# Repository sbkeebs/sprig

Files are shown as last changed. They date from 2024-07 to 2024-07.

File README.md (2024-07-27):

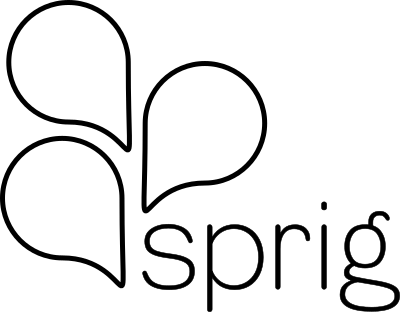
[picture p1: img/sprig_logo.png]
sprig logo


★ 10 columns in a modified Katana layout

★ inner columns are moved down a bit for an ergo-light curve

★ spacebar layout supports ISO enter for either or both bars

### This repo should contain:
- KiCAD 8 files for the PCB
- production files (gerbers, JLC BOM, CPL, etc) -- definitely double check the part numbers/availability before committing to fabrication! 
- printable files for the case (i am not very experienced in 3D design, but i have confirmed that it works!)
- firmware in both qmk/vial and zmk, and source for each

### To build your own zmk keymap
Fork [this repo](https://github.com/sbkeebs/sprig-zmk-config), and enable Actions. Modify `config/boards/arm/sprig/sprig.keymap`. Let it build (click Actions at the top of your repo).

ZMK Studio is not yet integrated!

This was built upon NCKiser's [STM32F072 template](https://github.com/NCKiser/STM32F072_template) as one of my first projects with an integrated MCU. If you'd like to get started with your own keyboard, [this video](https://www.youtube.com/watch?v=kGKN8SGkUD0) is a great place to start.

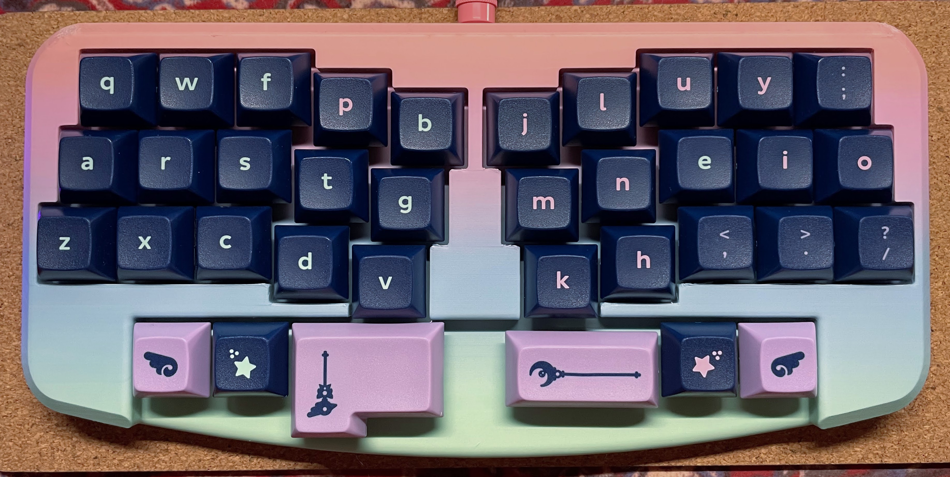
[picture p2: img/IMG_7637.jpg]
photo of sprig


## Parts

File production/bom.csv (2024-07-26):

Designator | Footprint | Quantity | Value | LCSC Part #
BOOT1, RST1 | SW_SPST_TL3342 | 2 | SW_SPST | C318884
C1, C3, C4, C5, C6, C7, C8 | 0402 | 7 | 100nF | C1525
C10, C9 | 0402 | 2 | 1uF | C52923
C2 | 0603 | 1 | 10uF | C57112
D1, D10, D11, D12, D13, D14, D15, D16, D17, D18, D19, D2, D20, D21, D22, D23, D24, D25, D26, D27, D28, D29, D3, D30, D32, D33, D34, D35, D36, D37, D4, D5, D6, D7, D8, D9 | D_SOD-323 | 36 | D_Small | C908234
F1 | 1206 | 1 | 500mA | C70076
J1 | USB_C_Receptacle_HRO_TYPE-C-31-M-12 | 1 | USB_C_Receptacle_USB2.0 | C165948
R1, R2, R3, R4 | 0402 | 4 | 5.1k | C144745
U1 | LQFP-48_7x7mm_P0.5mm | 1 | STM32F072CBT6 | C81720
U2 | SOT-143 | 1 | PRTR5V0U2X | C2827688
U3 | SOT-23 | 1 | XC6206PxxxMR-Regulator_Linear | C5446

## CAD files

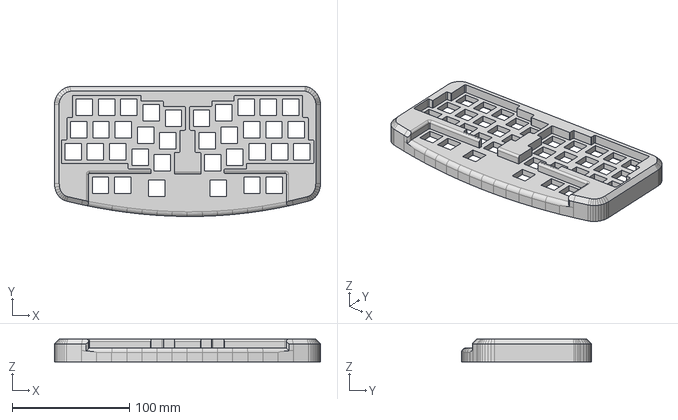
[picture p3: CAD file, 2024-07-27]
case/sprig_top_case.step
227.1 x 111.0 x 19.5 mm

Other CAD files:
case/sprig_top_case.stl

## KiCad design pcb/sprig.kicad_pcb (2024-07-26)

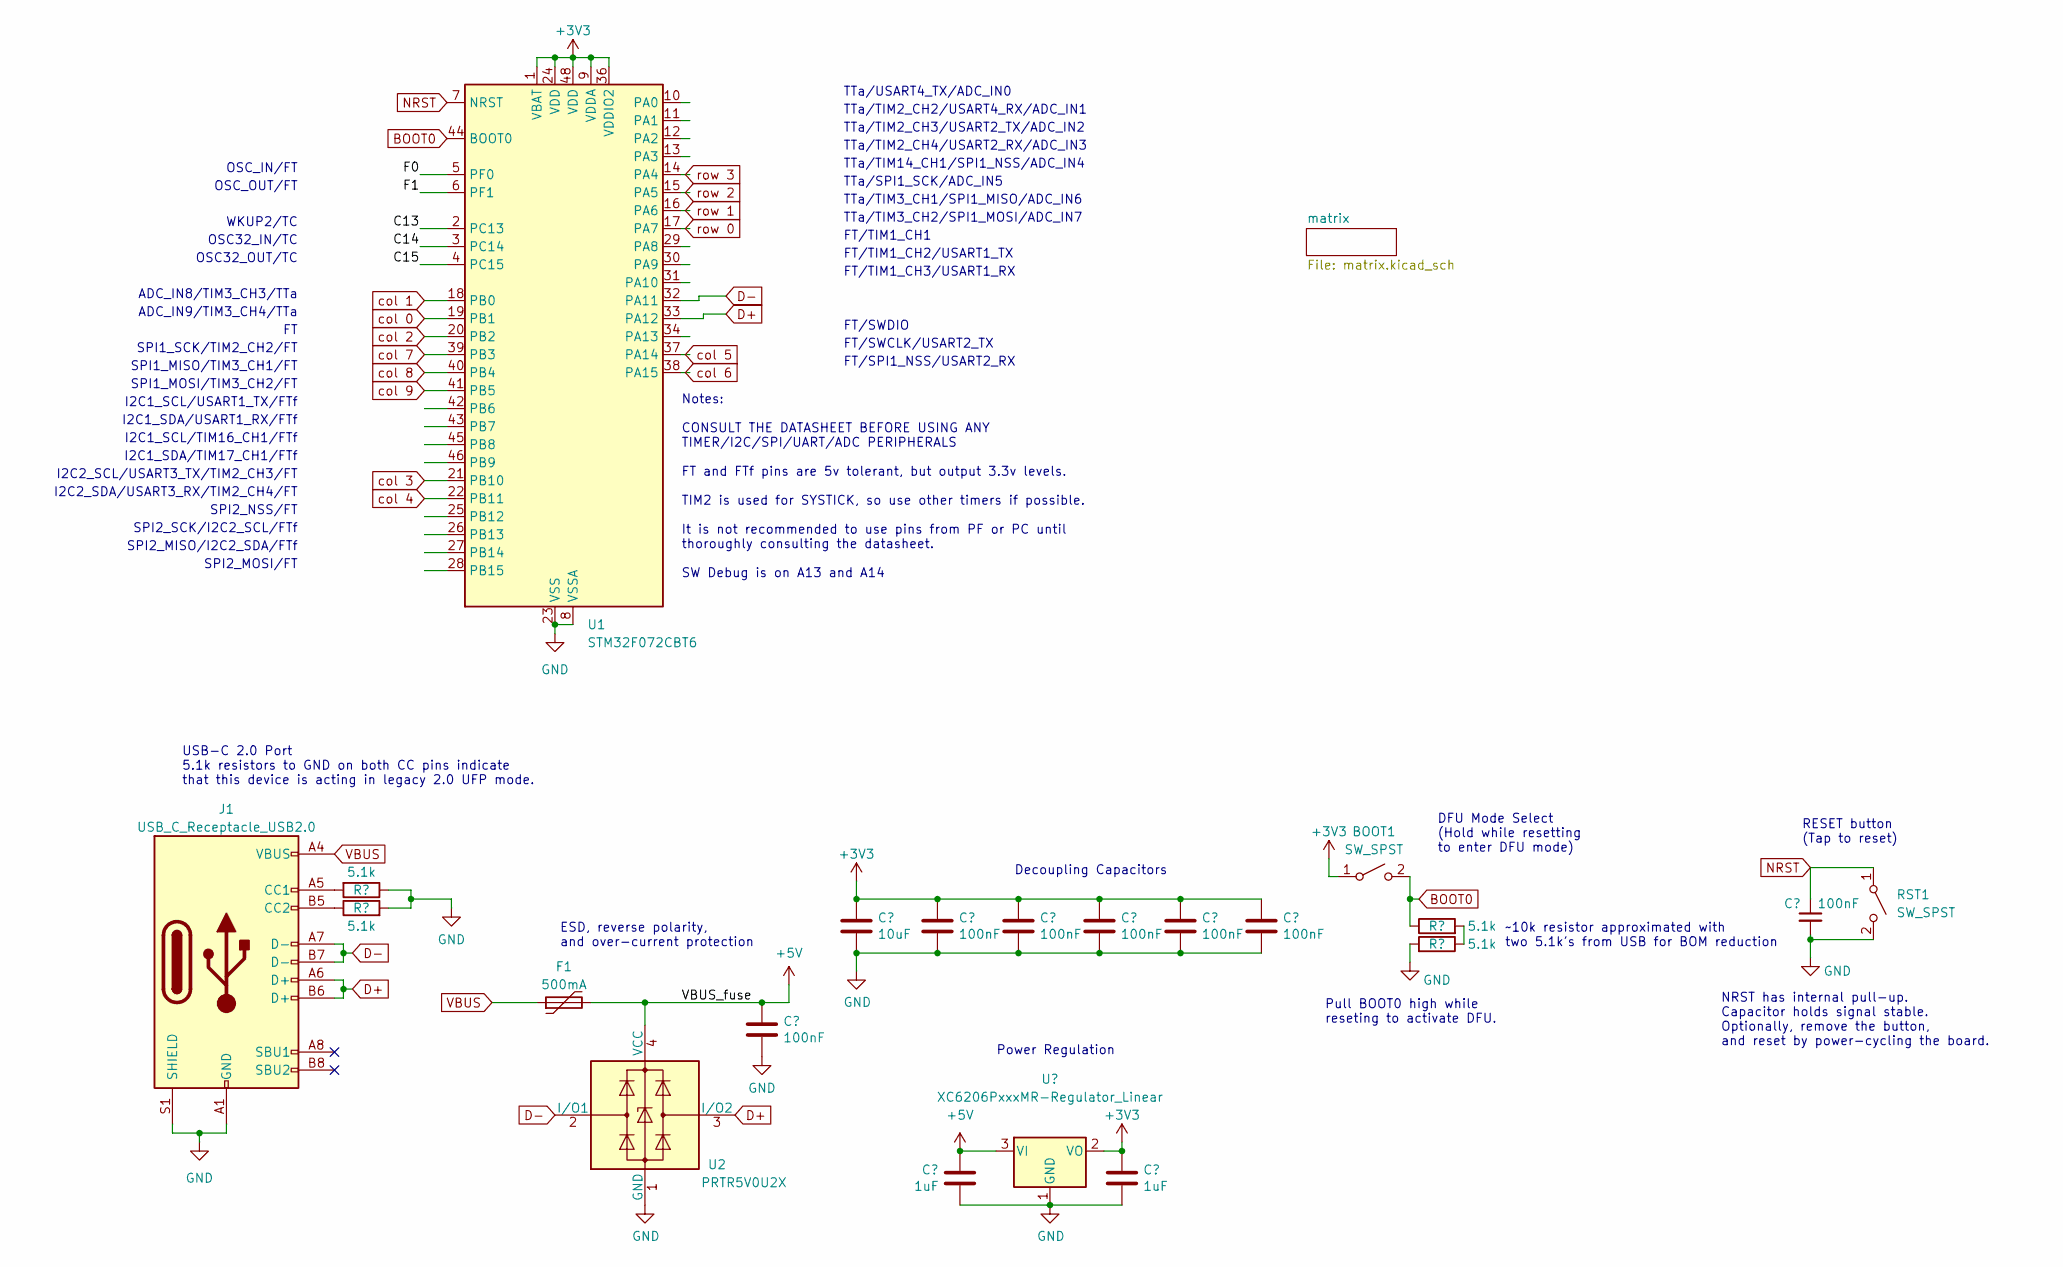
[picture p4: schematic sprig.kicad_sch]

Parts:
BOOT1: SW_SPST; SW_SPST_TL3342
C1, C3, C4, C5, C6, C7, C8: 100nF; C_0402_1005Metric; LCSC C307331
C2: 10uF; C_0603_1608Metric; LCSC C307331
C9, C10: 1uF; C_0402_1005Metric; LCSC C307331
F1: 500mA; Fuse_1206_3216Metric; LCSC C135341
J1: USB_C_Receptacle_USB2.0; USB_C_Receptacle_HRO_TYPE-C-31-M-12; JlcRotOffset 180
R1, R2, R3, R4: 5.1k; R_0402_1005Metric
RST1: SW_SPST; SW_SPST_TL3342
U1: STM32F072CBT6; LQFP-48_7x7mm_P0.5mm; JlcRotOffset 90
U2: PRTR5V0U2X; SOT-143; LCSC C2827688
U3: XC6206PxxxMR-Regulator_Linear; SOT-23; LCSC C5446

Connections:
+3V3: BOOT1.1 (A), C2.1, C3.1, C4.1, C5.1, C6.1, C7.1, C10.1, U1.1 (VBAT), U1.9 (VDDA), U1.24 (VDD), U1.36 (VDDIO2), U1.48 (VDD), U3.2 (VO)
+5V: C8.1, C9.1, F1.2, U2.4 (VCC), U3.3 (VI)
/C13: U1.2 (PC13)
/C14: U1.3 (PC14)
/C15: U1.4 (PC15)
/F0: U1.5 (PF0)
/F1: U1.6 (PF1)
BOOT0: BOOT1.2 (B), R3.1, U1.44 (BOOT0)
D+: J1.A6 (D+), J1.B6 (D+), U1.33 (PA12), U2.3 (I/O2)
D-: J1.A7 (D-), J1.B7 (D-), U1.32 (PA11), U2.2 (I/O1)
GND: C1.2, C2.2, C3.2, C4.2, C5.2, C6.2, C7.2, C8.2, C9.2, C10.2, J1.A1 (GND), J1.A12 (GND), J1.B1 (GND), J1.B12 (GND), J1.S1 (SHIELD), R1.1, R2.2, R4.2, RST1.2 (B), U1.8 (VSSA), U1.23 (VSS), U1.35 (VSS), U1.47 (VSS), U2.1 (GND), U3.1 (GND)
NRST: C1.1, RST1.1 (A), U1.7 (NRST)
unnamed: J1.A5 (CC1), R1.2
unnamed: J1.B5 (CC2), R2.1
unnamed: R3.2, R4.1
VBUS: F1.1, J1.A4 (VBUS), J1.A9 (VBUS), J1.B4 (VBUS), J1.B9 (VBUS)
col 0: U1.19 (PB1); also elsewhere on the board
col 1: U1.18 (PB0); also elsewhere on the board
col 2: U1.20 (PB2); also elsewhere on the board
col 3: U1.21 (PB10); also elsewhere on the board
col 4: U1.22 (PB11); also elsewhere on the board
col 5: U1.37 (PA14); also elsewhere on the board
col 6: U1.38 (PA15); also elsewhere on the board
col 7: U1.39 (PB3); also elsewhere on the board
col 8: U1.40 (PB4); also elsewhere on the board
col 9: U1.41 (PB5); also elsewhere on the board
row 0: U1.17 (PA7); also elsewhere on the board
row 1: U1.16 (PA6); also elsewhere on the board
row 2: U1.15 (PA5); also elsewhere on the board
row 3: U1.14 (PA4); also elsewhere on the board

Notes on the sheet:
SPI1_SCK/TIM2_CH2/FT
FT/TIM1_CH1
FT/TIM1_CH3/USART1_RX
SPI2_NSS/FT
Notes: CONSULT THE DATASHEET BEFORE USING ANY TIMER/I2C/SPI/UART/ADC PERIPHERALS FT and FTf pins are 5v tolerant, but output 3.3v levels. TIM2 is used for SYSTICK, so use other timers if possible. It is not recommended to use pins from PF or PC until thoroughly consulting the datasheet. SW Debug is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
TTa/TIM2_CH4/USART2_RX/ADC_IN3
NRST has internal pull-up. Capacitor holds signal stable. Optionally, remove the button, and reset by power-cycling the board.
FT/SWDIO
Decoupling Capacitors
SPI1_MOSI/TIM3_CH2/FT
ADC_IN9/TIM3_CH4/TTa
I2C2_SCL/USART3_TX/TIM2_CH3/FT
SPI2_MISO/I2C2_SDA/FTf
FT/SWCLK/USART2_TX
I2C1_SCL/TIM16_CH1/FTf
~10k resistor approximated with two 5.1k's from USB for BOM reduction
TTa/TIM2_CH2/USART4_RX/ADC_IN1
USB-C 2.0 Port 5.1k resistors to GND on both CC pins indicate that this device is acting in legacy 2.0 UFP mode.
TTa/TIM2_CH3/USART2_TX/ADC_IN2
OSC_IN/FT
DFU Mode Select (Hold while resetting to enter DFU mode)
WKUP2/TC
I2C2_SDA/USART3_RX/TIM2_CH4/FT
ADC_IN8/TIM3_CH3/TTa
RESET button (Tap to reset)
Pull BOOT0 high while reseting to activate DFU.
I2C1_SDA/TIM17_CH1/FTf
TTa/SPI1_SCK/ADC_IN5
TTa/TIM3_CH1/SPI1_MISO/ADC_IN6
TTa/TIM3_CH2/SPI1_MOSI/ADC_IN7
OSC32_OUT/TC
FT/SPI1_NSS/USART2_RX
SPI1_MISO/TIM3_CH1/FT
OSC32_IN/TC
TTa/TIM14_CH1/SPI1_NSS/ADC_IN4
I2C1_SDA/USART1_RX/FTf
SPI2_MOSI/FT
FT/TIM1_CH2/USART1_TX
Power Regulation
SPI2_SCK/I2C2_SCL/FTf

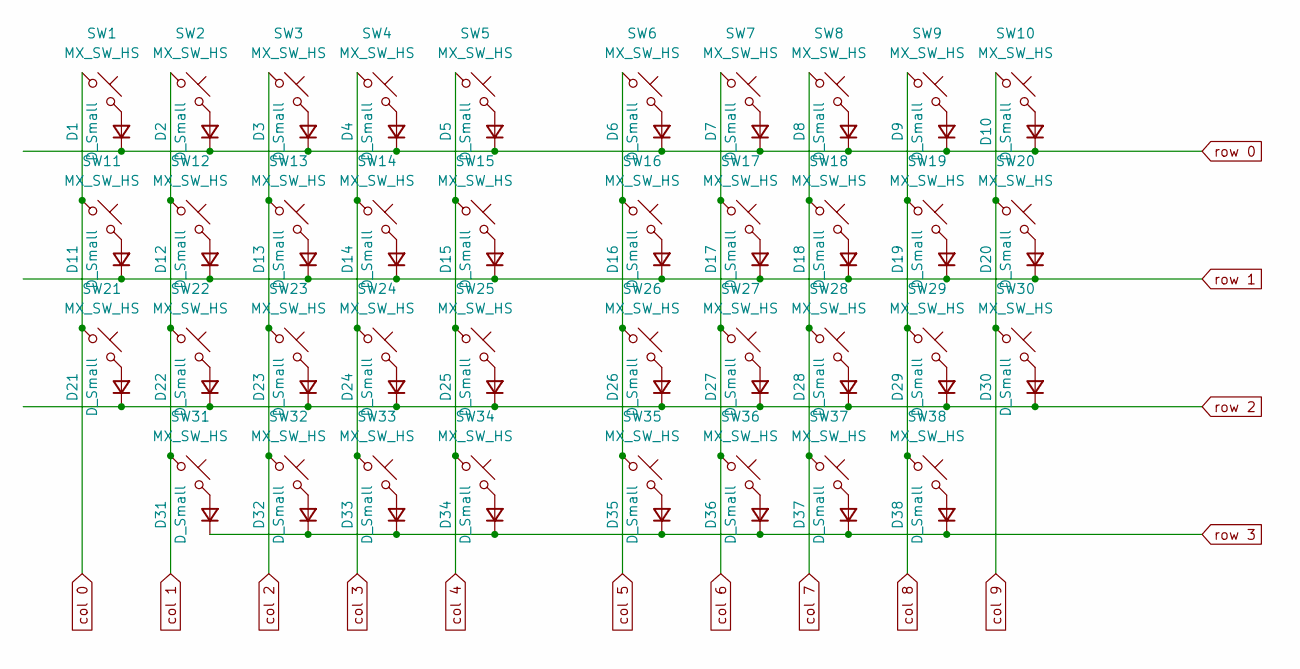
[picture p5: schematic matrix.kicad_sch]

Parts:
D1, D2, D3, D4, D5, D6, D7, D8, D9, D10, D11, D12, D13, D14, D15, D16, D17, D18, D19, D20, D21, D22, D23, D24, D25, D26, D27, D28, D29, D30, D31, D32, D33, D34, D35, D36, D37, D38: D_Small; D_SOD-323
SW1, SW2, SW3, SW4, SW5, SW6, SW7, SW8, SW9, SW10, SW11, SW12, SW13, SW14, SW15, SW16, SW17, SW18, SW19, SW20, SW21, SW22, SW23, SW24, SW25, SW26, SW27, SW28, SW29, SW30, SW31, SW32, SW33, SW34, SW35, SW36, SW37, SW38: MX_SW_HS; SW_MX_HS_CPG151101S11_1u

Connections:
unnamed: D1.2 (A), SW1.2
unnamed: D2.2 (A), SW2.2
unnamed: D3.2 (A), SW3.2
unnamed: D4.2 (A), SW4.2
unnamed: D5.2 (A), SW5.2
unnamed: D6.2 (A), SW6.2
unnamed: D7.2 (A), SW7.2
unnamed: D8.2 (A), SW8.2
unnamed: D9.2 (A), SW9.2
unnamed: D10.2 (A), SW10.2
unnamed: D11.2 (A), SW11.2
unnamed: D12.2 (A), SW12.2
unnamed: D13.2 (A), SW13.2
unnamed: D14.2 (A), SW14.2
unnamed: D15.2 (A), SW15.2
unnamed: D16.2 (A), SW16.2
unnamed: D17.2 (A), SW17.2
unnamed: D18.2 (A), SW18.2
unnamed: D19.2 (A), SW19.2
unnamed: D20.2 (A), SW20.2
unnamed: D21.2 (A), SW21.2
unnamed: D22.2 (A), SW22.2
unnamed: D23.2 (A), SW23.2
unnamed: D24.2 (A), SW24.2
unnamed: D25.2 (A), SW25.2
unnamed: D26.2 (A), SW26.2
unnamed: D27.2 (A), SW27.2
unnamed: D28.2 (A), SW28.2
unnamed: D29.2 (A), SW29.2
unnamed: D30.2 (A), SW30.2
unnamed: D31.2 (A), SW31.2
unnamed: D32.2 (A), SW32.2
unnamed: D33.2 (A), SW33.2
unnamed: D34.2 (A), SW34.2
unnamed: D35.2 (A), SW35.2
unnamed: D36.2 (A), SW36.2
unnamed: D37.2 (A), SW37.2
unnamed: D38.2 (A), SW38.2
col 0: SW1.1, SW11.1, SW21.1; also elsewhere on the board
col 1: SW2.1, SW12.1, SW22.1, SW31.1; also elsewhere on the board
col 2: SW3.1, SW13.1, SW23.1, SW32.1; also elsewhere on the board
col 3: SW4.1, SW14.1, SW24.1, SW33.1; also elsewhere on the board
col 4: SW5.1, SW15.1, SW25.1, SW34.1; also elsewhere on the board
col 5: SW6.1, SW16.1, SW26.1, SW35.1; also elsewhere on the board
col 6: SW7.1, SW17.1, SW27.1, SW36.1; also elsewhere on the board
col 7: SW8.1, SW18.1, SW28.1, SW37.1; also elsewhere on the board
col 8: SW9.1, SW19.1, SW29.1, SW38.1; also elsewhere on the board
col 9: SW10.1, SW20.1, SW30.1; also elsewhere on the board
row 0: D1.1 (K), D2.1 (K), D3.1 (K), D4.1 (K), D5.1 (K), D6.1 (K), D7.1 (K), D8.1 (K), D9.1 (K), D10.1 (K); also elsewhere on the board
row 1: D11.1 (K), D12.1 (K), D13.1 (K), D14.1 (K), D15.1 (K), D16.1 (K), D17.1 (K), D18.1 (K), D19.1 (K), D20.1 (K); also elsewhere on the board
row 2: D21.1 (K), D22.1 (K), D23.1 (K), D24.1 (K), D25.1 (K), D26.1 (K), D27.1 (K), D28.1 (K), D29.1 (K), D30.1 (K); also elsewhere on the board
row 3: D31.1 (K), D32.1 (K), D33.1 (K), D34.1 (K), D35.1 (K), D36.1 (K), D37.1 (K), D38.1 (K); also elsewhere on the board

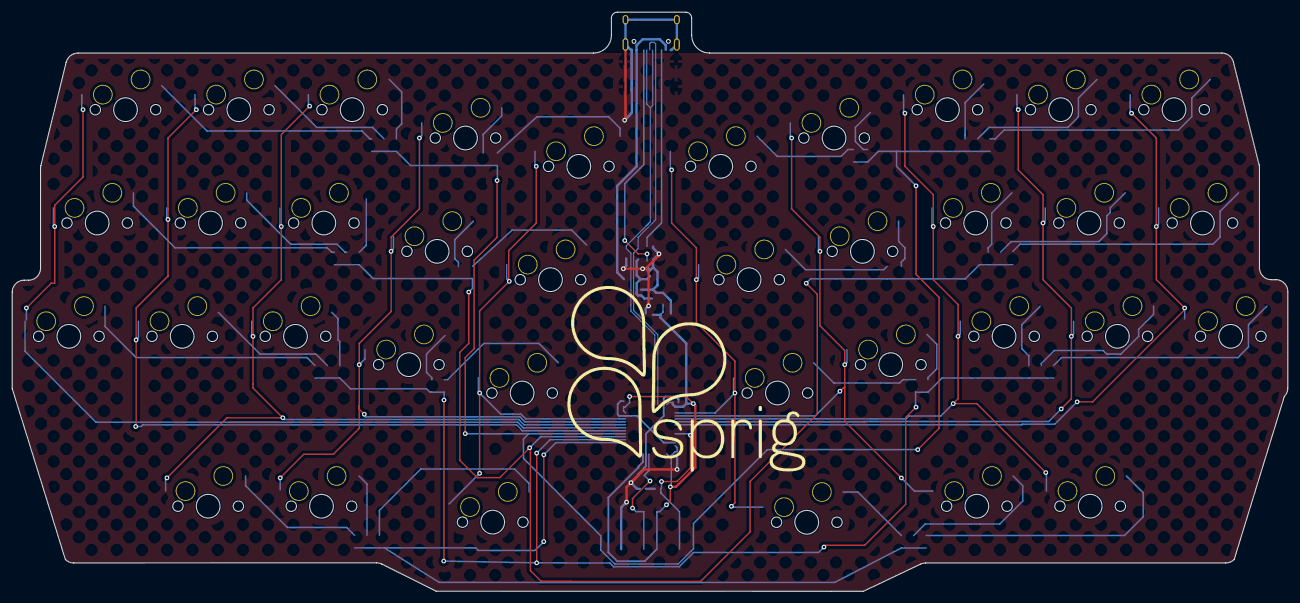
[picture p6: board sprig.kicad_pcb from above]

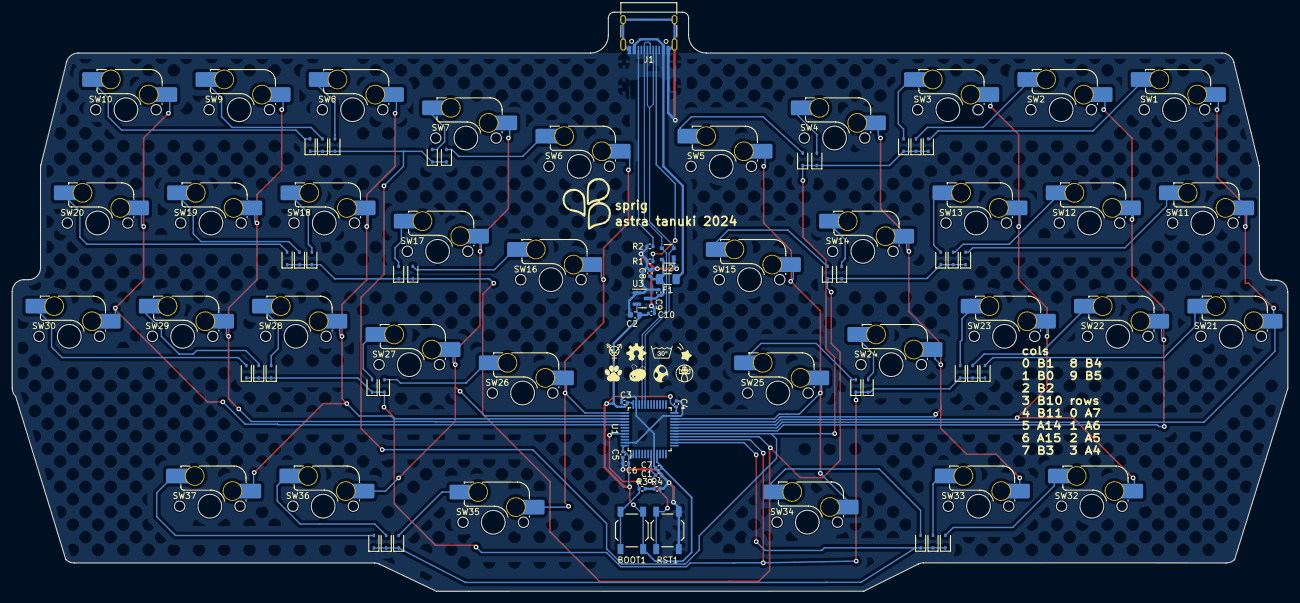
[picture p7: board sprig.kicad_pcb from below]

Board: 2 copper layers, 214.4 x 97.4 mm, 93 parts (93 on the bottom side), 61 nets.

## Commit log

2024-07-26 first version
    [aio_case_top.stl, bom.csv, designators.csv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]
2024-07-26 fix vial fw
    [sprig.kicad_pcb, sprig.kicad_sch]
2024-07-27 replace old case file, include .step also
    [sprig_top_case.step, sprig_top_case.stl]
2024-07-27 update pcb files
    [matrix.kicad_sch, sprig.kicad_sch]
